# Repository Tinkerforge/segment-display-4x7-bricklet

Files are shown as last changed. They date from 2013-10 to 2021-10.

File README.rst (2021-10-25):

Segment Display 4x7 Bricklet
============================

This repository contains the firmware source code and the hardware design
files. The documentation generator configs can be found at
https://github.com/Tinkerforge/generators

Repository Content
------------------

software/:
 * examples/: Examples for all supported languages
 * build/: Compiled files
 * src/: Source code of firmware
 * Makefile: Makefile to build project

hardware/:
 * Contains KiCad project files and additionally schematics as PDF

datasheets/:
 * Contains datasheets for sensors and complex ICs that are used

Hardware
--------

The hardware is designed with the open source EDA Suite KiCad
(http://www.kicad.org). Before you are able to open the files,
you have to install the Tinkerforge kicad-libraries
(https://github.com/Tinkerforge/kicad-libraries). You can either clone
them directly in hardware/ or clone them in a separate folder and
symlink them into hardware/
(ln -s kicad_path/kicad-libraries project_path/hardware). After that you
can open the .pro file in hardware/ with KiCad and from there view and
modify the schematics and the PCB layout.

Software
--------

If you want to do your own Brick/Bricklet firmware development we highly
recommend that you use our build environment setup script and read the
tutorial (https://www.tinkerforge.com/en/doc/Tutorials/Tutorial_Build_Environment/Tutorial.html).

To compile the C code we recommend you to install the newest GNU Arm Embedded
Toolchain (https://launchpad.net/gcc-arm-embedded/+download).
You also need to install bricklib (https://github.com/Tinkerforge/bricklib)
and brickletlib (https://github.com/Tinkerforge/brickletlib).

You can either clone it directly in software/src/ or clone it in a
separate folder and symlink it into software/src/
(ln -s bricklib_path/bricklib project_path/software/src/ and
ln -s brickletlib_path/brickletlib project_path/software/src/).
Finally make sure to have CMake installed
(http://www.cmake.org/cmake/resources/software.html).

After that you can build the firmware by invoking make in software/.
The firmware (.bin) can then be found in software/build/ and uploaded
with brickv (click button "Flashing" on start screen).

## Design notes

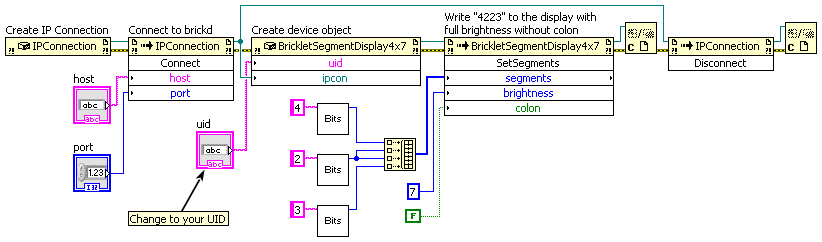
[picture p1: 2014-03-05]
software/examples/labview/Example Simple.vi.png

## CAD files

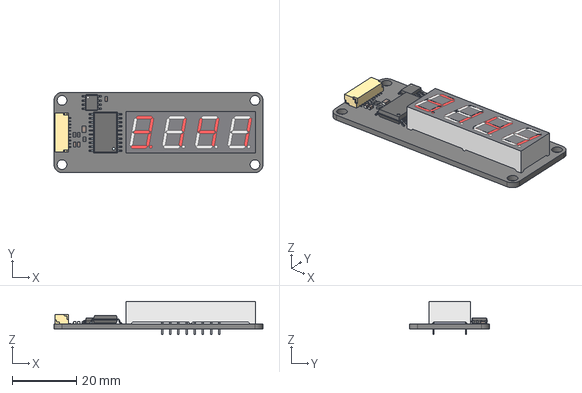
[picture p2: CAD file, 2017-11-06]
hardware/segment-display-4x7.step
65.0 x 25.0 x 10.4 mm

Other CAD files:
hardware/segment-display-4x7.FCStd

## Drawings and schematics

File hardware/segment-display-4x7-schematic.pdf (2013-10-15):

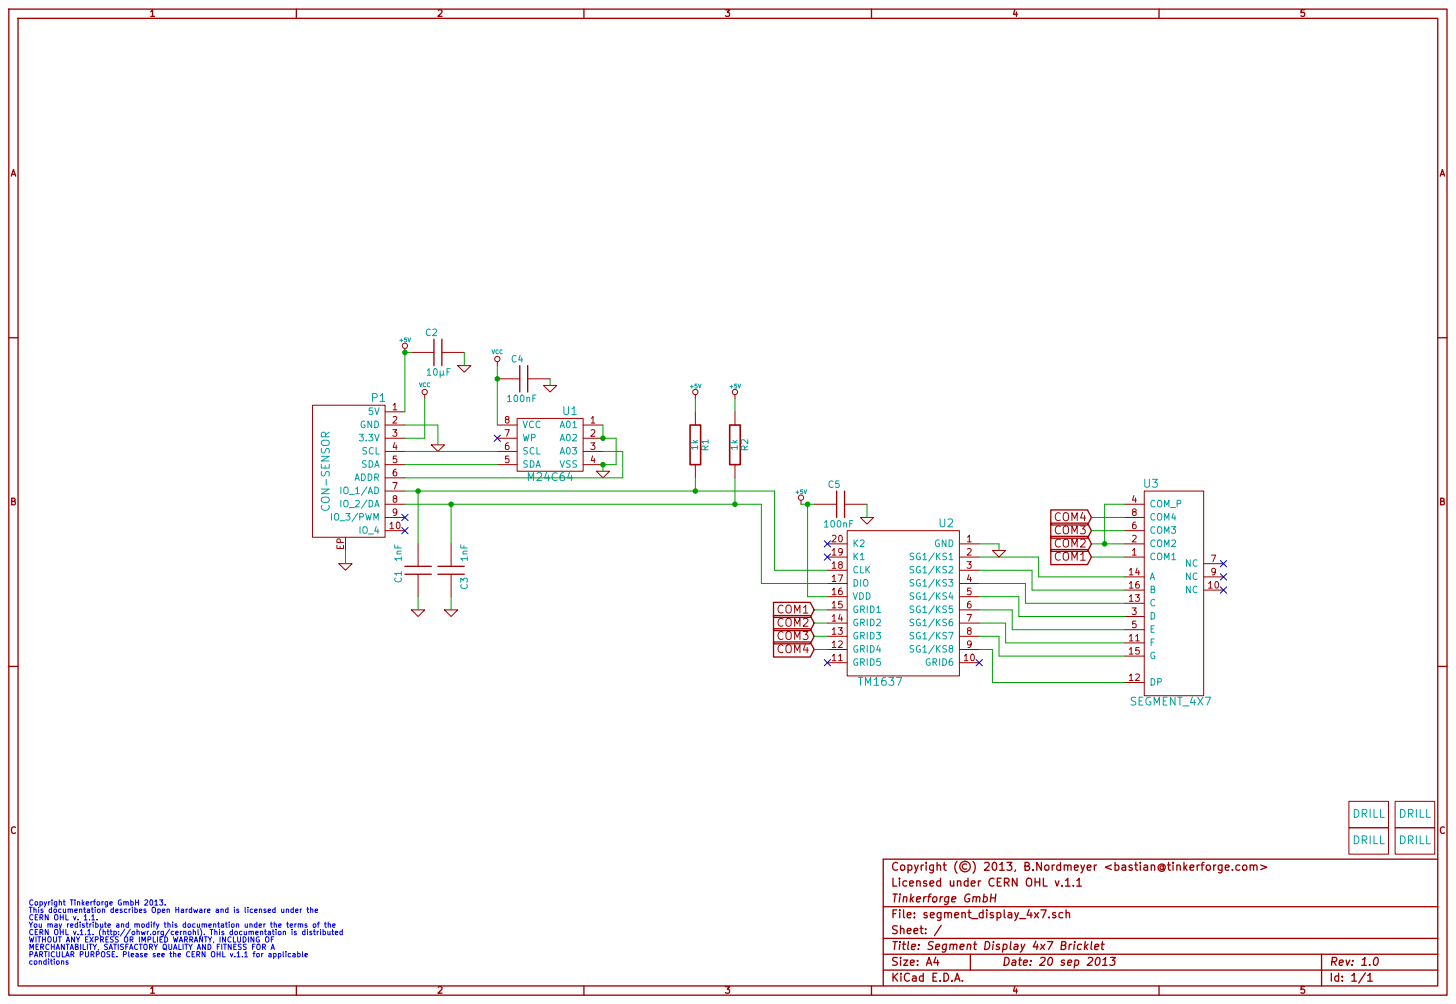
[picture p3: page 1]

VCC Copyright Tinkerforge GmbH 2013. This documentation describes Open Hardware and is licensed under the CERN OHL v. 1.1. You may redistribute and modify this documentation under the terms of the CERN OHL v.1.1. (http://ohwr.org/cernohl). This documentation is distributed WITHOUT ANY EXPRESS OR IMPLIED WARRANTY, INCLUDING OF MERCHANTABILITY, SATISFACTORY QUALITY AND FITNESS FOR A

Copyright (©) 2013, B.Nordmeyer <bastian@tinkerforge.com>
Licensed under CERN OHL v.1.1
Tinkerforge GmbH
File: segment_display_4x7.sch
Sheet: /
Title: Segment Display 4x7 Bricklet
KiCad E.D.A.

PARTICULAR PURPOSE. Please see the CERN OHL v.1.1 for applicable

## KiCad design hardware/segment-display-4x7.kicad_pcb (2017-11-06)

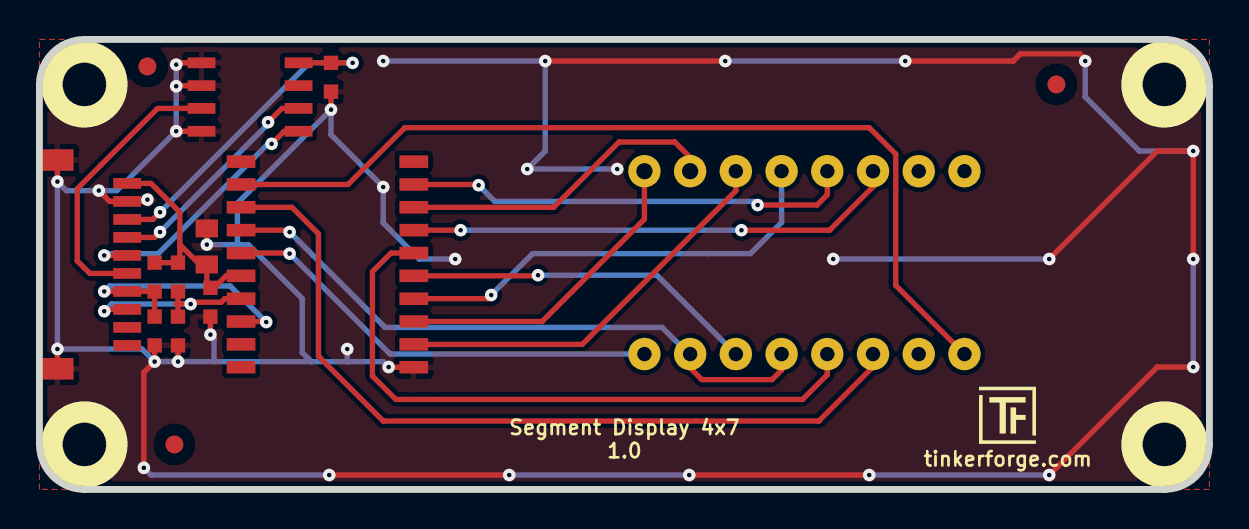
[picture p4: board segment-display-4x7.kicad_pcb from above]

Board: 2 copper layers, 65.0 x 25.0 mm, 20 parts (0 on the bottom side), 20 nets.

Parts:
C1, C3: 1nF; C0603
C2: 10µF; C0805
C4: 100nF; C0603
C5: 100nF; R0603
Fiducial_Mark: VAL**; Fiducial_Mark
Fiducial_Mark#2, Fiducial_Mark#3: VAL**; Fiducial_Mark
P1: CON-SENSOR
R1, R2: 1k; R0603
U1: M24C64; SOIC8
U2: TM1637; SOP20
U3: SEGMENT_4X7
U4, U5, U6, U7: DRILL; DRILL_NP
VAL: CE_5mm
VAL#2: WEEE_7mm

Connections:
+5V: C2.1, C5.1, P1.1, R1.1, R2.1, U2.16
COM1: U2.15, U3.1
COM2: U2.14, U3.2, U3.4
COM3: U2.13, U3.6
COM4: U2.12, U3.8
GND: C1.1, C2.2, C3.1, C4.2, C5.2, P1.2, P1.EP, U1.1, U1.2, U1.4, U2.1
unnamed: C1.2, P1.7, R1.2, U2.18
unnamed: C3.2, P1.8, R2.2, U2.17
unnamed: P1.4, U1.6
unnamed: P1.5, U1.5
unnamed: P1.6, U1.3
unnamed: U2.2, U3.14
unnamed: U2.3, U3.16
unnamed: U2.4, U3.13
unnamed: U2.5, U3.3
unnamed: U2.6, U3.5
unnamed: U2.7, U3.11
unnamed: U2.8, U3.15
unnamed: U2.9, U3.12
VCC: C4.1, P1.3, U1.8

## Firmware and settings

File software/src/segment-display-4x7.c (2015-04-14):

/* segment-display-4x7-bricklet
 * Copyright (C) 2013 Olaf Lüke <olaf@tinkerforge.com>
 * Copyright (C) 2015 Matthias Bolte <matthias@tinkerforge.com>
 *
 * segment-display-4x7.c: Implementation of Segment Display 4x7 Bricklet messages
 *
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
 * You should have received a copy of the GNU Lesser General Public
 * License along with this library; if not, write to the
 * Free Software Foundation, Inc., 59 Temple Place - Suite 330,
 * Boston, MA 02111-1307, USA.
 */

#include "segment-display-4x7.h"

#include "bricklib/bricklet/bricklet_communication.h"
#include "bricklib/utility/util_definitions.h"
#include "bricklib/utility/init.h"
#include "bricklib/drivers/adc/adc.h"
#include "brickletlib/bricklet_entry.h"
#include "brickletlib/bricklet_simple.h"
#include "config.h"

const uint8_t digits[] = {0x3f,0x06,0x5b,0x4f,
                          0x66,0x6d,0x7d,0x07,
                          0x7f,0x6f,0x77,0x7c,
                          0x39,0x5e,0x79,0x71}; // 0~9,A,b,C,d,E,F

void invocation(const ComType com, const uint8_t *data) {
	switch(((MessageHeader*)data)->fid) {
		case FID_SET_SEGMENTS: {
			set_segments(com, (SetSegments*)data);
			return;
		}

		case FID_GET_SEGMENTS: {
			get_segments(com, (GetSegments*)data);
			return;
		}

		case FID_START_COUNTER: {
			start_counter(com, (StartCounter*)data);
			return;
		}

		case FID_GET_COUNTER_VALUE: {
			get_counter_value(com, (GetCounterValue*)data);
			return;
		}

		default: {
			BA->com_return_error(data, sizeof(MessageHeader), MESSAGE_ERROR_CODE_NOT_SUPPORTED, com);
			return;
		}
	}
}

void start_counter(const ComType com, const StartCounter *data) {
	BC->counter_from            = BETWEEN(-999, data->from, 9999);
	BC->counter_to              = BETWEEN(-999, data->to, 9999);
	BC->counter_increment       = BETWEEN(-999, data->increment, 9999);
	BC->counter_length          = data->length;

	if((BC->counter_length == 0) ||
	   (BC->counter_increment == 0) ||
	   (BC->counter_increment > 0 &&  BC->counter_from > BC->counter_to) ||
	   (BC->counter_increment < 0 &&  BC->counter_from < BC->counter_to)) {
		BC->counter_length_current = 0;
		BA->com_return_error(data, sizeof(MessageHeader), MESSAGE_ERROR_CODE_INVALID_PARAMETER, com);
		return;
	}

	BC->counter_current         = BC->counter_from;
	BC->counter_length_current  = BC->counter_length;

	set_counter(BC->counter_current);

	BA->com_return_setter(com, data);
}

void get_counter_value(const ComType com, const GetCounterValue *data) {
	GetCounterValueReturn gcvr;
	gcvr.header        = data->header;
	gcvr.header.length = sizeof(GetCounterValueReturn);
	gcvr.value         = BC->counter_current;

	BA->send_blocking_with_timeout(&gcvr,
	                               sizeof(GetCounterValueReturn),
	                               com);
}

void set_segments(const ComType com, const SetSegments *data) {
	BC->segments[0]  = data->segments[0] & 0x7F;
	BC->segments[1]  = data->segments[1] & 0x7F;
	BC->segments[2]  = data->segments[2] & 0x7F;
	BC->segments[3]  = data->segments[3] & 0x7F;
	BC->brightness   = MIN(data->brightness, 7);
	BC->colon = data->colon;

	update_digits();

	BC->counter_length_current = 0;

	BA->com_return_setter(com, data);
}

void get_segments(const ComType com, const GetSegments *data) {
	GetSegmentsReturn gsr;
	gsr.header        = data->header;
	gsr.header.length = sizeof(GetSegmentsReturn);

	gsr.segments[0]   = BC->segments[0];
	gsr.segments[1]   = BC->segments[1];
	gsr.segments[2]   = BC->segments[2];
	gsr.segments[3]   = BC->segments[3];
	gsr.brightness    = BC->brightness;
	gsr.colon  = BC->colon;

	BA->send_blocking_with_timeout(&gsr,
	                               sizeof(GetSegmentsReturn),
	                               com);
}

void constructor(void) {
	_Static_assert(sizeof(BrickContext) <= BRICKLET_CONTEXT_MAX_SIZE, "BrickContext too big");

    PIN_DIO.type = PIO_INPUT;
    PIN_DIO.attribute = PIO_DEFAULT;
    BA->PIO_Configure(&PIN_DIO, 1);
    PIN_DIO.pio->PIO_CODR = PIN_DIO.mask;

    PIN_CLK.type = PIO_INPUT;
    PIN_CLK.attribute = PIO_DEFAULT;
    BA->PIO_Configure(&PIN_CLK, 1);
    PIN_CLK.pio->PIO_CODR = PIN_CLK.mask;

	BC->segments[0] = 0;
	BC->segments[1] = 0;
	BC->segments[2] = 0;
	BC->segments[3] = 0;
	BC->brightness = 0;
	BC->colon = false;

    BC->tick = 0;

    i2c_clear_bus(&PIN_DIO, &PIN_CLK);

	update_digits();
}

void destructor(void) {
    PIN_DIO.type = PIO_INPUT;
    PIN_DIO.attribute = PIO_PULLUP;
    BA->PIO_Configure(&PIN_DIO, 1);

    PIN_CLK.type = PIO_INPUT;
    PIN_CLK.attribute = PIO_PULLUP;
    BA->PIO_Configure(&PIN_CLK, 1);
}

void i2c_clear_bus_delay(void) {
	SLEEP_US(10);
}

void i2c_clear_bus_9clock(Pin *sda, Pin *scl) {
	scl->type = PIO_OUTPUT_0;
	scl->attribute = PIO_DEFAULT;
	BA->PIO_Configure(scl, 1);
	i2c_clear_bus_delay();

	sda->type = PIO_INPUT;
	sda->attribute = PIO_PULLUP;
	BA->PIO_Configure(sda, 1);
	i2c_clear_bus_delay();

	for(uint8_t i = 0; i < 9; i++) {
		scl->type = PIO_INPUT;
		scl->attribute = PIO_PULLUP;
		BA->PIO_Configure(scl, 1);
		i2c_clear_bus_delay();

		scl->type = PIO_OUTPUT_0;
		scl->attribute = PIO_DEFAULT;
		BA->PIO_Configure(scl, 1);
		i2c_clear_bus_delay();
	}
}

void i2c_clear_bus_stop(Pin *sda, Pin *scl) {
	scl->type = PIO_OUTPUT_0;
	scl->attribute = PIO_DEFAULT;
	BA->PIO_Configure(scl, 1);
	i2c_clear_bus_delay();

	sda->type = PIO_OUTPUT_0;
	sda->attribute = PIO_DEFAULT;
	BA->PIO_Configure(sda, 1);
	i2c_clear_bus_delay();

	scl->type = PIO_INPUT;
	scl->attribute = PIO_PULLUP;
	BA->PIO_Configure(scl, 1);
	i2c_clear_bus_delay();

	sda->type = PIO_INPUT;
	sda->attribute = PIO_DEFAULT;
	BA->PIO_Configure(sda, 1);
	i2c_clear_bus_delay();
}

void i2c_clear_bus_start(Pin *sda, Pin *scl) {
	sda->type = PIO_INPUT;
	sda->attribute = PIO_DEFAULT;
	BA->PIO_Configure(sda, 1);
	i2c_clear_bus_delay();

	scl->type = PIO_INPUT;
	scl->attribute = PIO_PULLUP;
	BA->PIO_Configure(scl, 1);
	i2c_clear_bus_delay();

	sda->type = PIO_OUTPUT_0;
	sda->attribute = PIO_DEFAULT;
	BA->PIO_Configure(sda, 1);
	i2c_clear_bus_delay();

	scl->type = PIO_OUTPUT_0;
	scl->attribute = PIO_DEFAULT;
	BA->PIO_Configure(scl, 1);
	i2c_clear_bus_delay();
}

void i2c_clear_bus(Pin *sda, Pin *scl) {
	i2c_clear_bus_start(sda, scl);
	i2c_clear_bus_9clock(sda, scl);
	i2c_clear_bus_start(sda, scl);
	i2c_clear_bus_stop(sda, scl);
}

bool i2c_clk_value(void) {
	return PIN_CLK.pio->PIO_PDSR & PIN_CLK.mask;
}

void i2c_clk_high(void) {
	PIN_CLK.pio->PIO_ODR = PIN_CLK.mask;
}

void i2c_clk_low(void) {
	PIN_CLK.pio->PIO_OER = PIN_CLK.mask;
}

bool i2c_dio_value(void) {
	return PIN_DIO.pio->PIO_PDSR & PIN_DIO.mask;
}

void i2c_dio_high(void) {
	PIN_DIO.pio->PIO_ODR = PIN_DIO.mask;
}

void i2c_dio_low(void) {
	PIN_DIO.pio->PIO_OER = PIN_DIO.mask;
}

void i2c_sleep_halfclock(void) {
	SLEEP_NS(I2C_HALF_CLOCK_400KHZ);
}

void i2c_stop(void) {
	i2c_clk_low();
	i2c_dio_low();
	i2c_sleep_halfclock();
	i2c_clk_high();
	i2c_sleep_halfclock();
	i2c_dio_high();
	i2c_sleep_halfclock();
}
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

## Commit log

2013-10-15 add hardware files
    [segment_display_4x7.kicad_pcb, segment_display_4x7.sch]
2014-03-27 Add I2C clear bus in constructor
2014-04-02 perl: Unify print style
2015-08-07 Use full device class name in Python examples
2015-09-30 drc run
    [segment_display_4x7.kicad_pcb]
2016-01-26 php: Add temperature example
2016-05-18 c: Add missing device destroy call
2017-11-06 Add 3d information (final)
    [segment_display_4x7.kicad_pcb, segment_display_4x7.sch]
2017-11-06 Add 3d model (*.step & *.FCStd)
    [segment_display_4x7.FCStd, segment_display_4x7.step]
2018-02-20 Cleanup KiCad libraries config
    Ensure LibDir=kicad-libraries and LibName1=tinkerforge.
    Remove special library.
2018-05-11 Rename files
    [segment-display-4x7.FCStd, segment-display-4x7.kicad_pcb, segment-display-4x7.sch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]
2021-10-25 Update KiCad link
    https://www.kicad.org/blog/2021/10/Avoid-links-to-former-kicad-domain/
